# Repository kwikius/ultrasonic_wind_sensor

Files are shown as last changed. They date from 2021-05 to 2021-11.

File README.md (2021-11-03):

# Ultrasonic Wind Speed and Direction Sensor from a car reversing kit and an Arduino.

Ultrasonic wind sensors are known for their accuracy and reliability. However they also tend to be quite expensive.

The Ultrasonic wind sensor described here can be built for around £20($20) and has excellent performance.

The main components of the project are an Ebay car reversing kit, available for around £9(10$US) and an arduino Pro Mini or clone for around 5$US.

Click the below image to watch a video of the project on YouTube:

[Youtube - Ultrasonic Wind Speed and Direction Sensor from a car reversing kit](https://www.youtube.com/watch?v=_kloM0Tk8lo&list=PL-N-nQ0dVeh7bO8eM10oHQ2tNhluuLc5f 
"Youtube - Ultrasonic Wind Speed and Direction Sensor from a car reversing kit")

Full details about building the electronics and mechanical hardware can be found at Hackaday.io

https://hackaday.io/project/181677-wind-sensor-using-car-reversing-kit

The project is designed to be managed in the Arduino IDE.

### Installing and building the project

Firstly clone the Github Project

```>$ git clone https://github.com/kwikius/ultrasonic_wind_sensor.git ```

Next install the quan-trunk submodule using the following command

```>$ git submodule update --init --recursive```

-------------------------

### Building and uploading the Atmega326 part of the Project

Start the Arduino IDE. Click on 'File > Preferences' and modify the sketchbook location so that it leads to the ultrasonic_wind_sensor directory.
Close Arduino and reopen.

When Arduino reopens , click on 'File > Open' , navigate to the ultrasonic_wind_sensor/ArduUltrasonicWindSensor subdirectory and select "ArduUltrasonicWindSensor.ino".

Next click on 'Tools > Board' and select   (AVR boards) > "Arduino Pro or Pro Mini".

Next click on 'Tools > Processor' and select "ATmega328P(5v, 16 MHz)"

Now select 'Sketch > Verify/Compile' to compile. 

The code can be uploaded by attaching a serial cable to the Arduino Pro Mini and clicking Sketch > Upload.

By default the sketch provides text output via the serial port.

For [web server](https://github.com/kwikius/ultrasonic_wind_sensor/blob/master/web_server/web_server.ino) ,
uncomment //#define WIND_SENSOR_WEB_SERVER_OUTPUT in ArduUltrasonicWindSensor.ino

------------------------------

TODO Proper installation instructions for [web server](https://github.com/kwikius/ultrasonic_wind_sensor/blob/master/web_server/web_server.ino)

### Building and uploading the web server.

Assumes you are using the ESP-01. You will need a suitable programming fixture, 
[such as described here](https://www.allaboutcircuits.com/projects/flashing-the-ESP-01-firmware-to-SDK-v2.0.0-is-easier-now/)

You also need to install the ESP8266 plugin for Arduino if not already installed, 
[as described here](https://create.arduino.cc/projecthub/electropeak/getting-started-w-nodemcu-esp8266-on-arduino-ide-28184f)

You need the following libraries in libraries subdirectory 
* https://github.com/me-no-dev/ESPAsyncTCP
* https://github.com/me-no-dev/ESPAsyncWebServer
* https://github.com/Links2004/arduinoWebSockets

Start the Arduino IDE. Click on 'File > Preferences' and modify the sketchbook location so that it leads to the ultrasonic_wind_sensor directory.
Close Arduino and reopen.

When Arduino reopens , click on 'File > Open' , navigate to the ultrasonic_wind_sensor/web_server subdirectory 
and select "web_server.ino".

Next click on 'Tools > Processor' and select "Generic ESP8266 Module"

Now select 'Sketch > Verify/Compile' to compile. 

To Upload the code, connect the programming fixture via 3.3V Serial cable to your PC.
Insert the ESP-01 in the fixture.
Hold down both the Flash and Reset buttons on the programming fixture with the ESP-01 inserted.
Release the Reset button while keeping Flash button pressed. 

While keeping Flash button pressed. Select 'Sketch > Upload'.

Watch the output from the Arduino IDE. Once it is apparent that the code is uploading, you can release the Flash button, 
as it is only required to be pressed when the ESP-01 boots.

For initial programming of the webserver you will need to use the programming fixture to set the Network parameters.

The WebServer requires the nextwork ID and password to connect to. If there are no saved parameters the web server will ask for those.
N.B If using the Arduino Serial monitor for Serial IO, then set Carriage return as the end of line type and set baud rate at 115,200 baud.
You have the choice to save the network parameters in EEPROM or not. If you choose not to save the parameters, they will be available 
until the web server is reset. If you choose to save the parameters they will be saved in EEPROM and will be used by default at reset.
You can change the network you connect to by pressing Return ('\r') three times in 1st 5 seconds after reset. 
Again if you wish to save the new settings the old network settings will be overwritten, otherwise the settings you entered will be used 
unitil next reset.

Once the network parameters have been saved in EEprom, you can put the ESP-01 back in the wind sensor board.

(Note that you must be running the modified ArduUltrasonicWindSensor.ino for Atmega328 to talk to the webserver as described above)

With the wind sensor powered up, you should see the ESP-01 LED blinking. Once the LED goes out, it indicates the web server is connected to the network

The webserver is designed to support MDNS ( NOTE: Unfortunately this doesnt work in Android)

Open a web browser and enter "windsensor.local" as the URL. 
All being well, you should see the windsensor web page with real time data streaming from the wind sensor.

For Android, you will need to download an App such as [Fing](https://www.fing.com/products/fing-app)

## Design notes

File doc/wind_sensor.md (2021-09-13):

# Ultrasonic Wind speed and direction sensor from car reversing sensor kit and an Arduino Mini

A £10 car sensor reversing kit can be converted into an inexpensive but highly accurate wind speed and direction sensor.

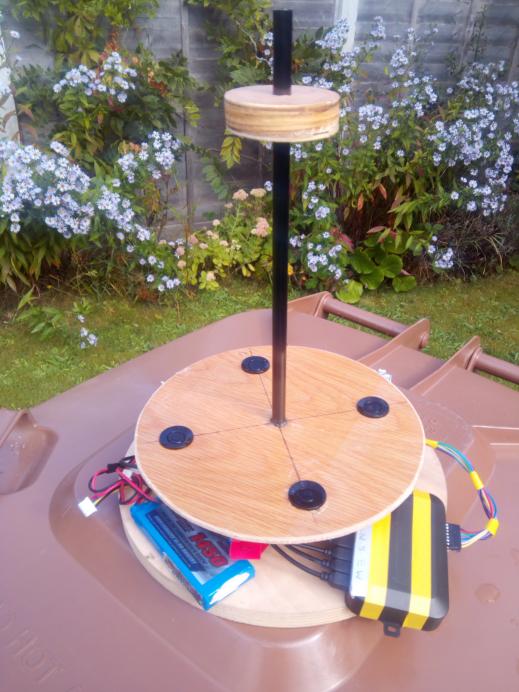
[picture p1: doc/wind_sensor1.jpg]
Ultrasonic Wind speed and direction sensor from car reversing sensor kit


These car reversing kits are abundant on ebay at a low price.

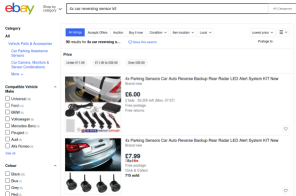
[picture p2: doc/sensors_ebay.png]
Car sensor reversing kits on ebay


In the kit are :

* 4 waterproof 40 kHz ultrasonic transducers with long leads.
* A 12v power supply lead for connecting to a car battery.
* A LED display with long cable on off switch and speaker. (The display has a 14 pin mcu with same pinout as a PIC16C84, but the display is not used in this project.)
* A control box with sockets for the transducers, display and power. 
* A handy hole sawdrill which makes it easy to drill holes for the transducers.

The pcb inside the control box has:
* sockets for 
   * the 4 transducers, 
   * power 
   * 4 wire socket for serial IO ( for the display)
* A pulse transformer for each transducer.
* A multiplexer for the pulse inputs.
* A demultiplexer for the outputs.
* A bandpass filter for filtering the returned signal
* An envelope detector.

The schematic of the transducer circuit :
schematic of the transducer circuit

The schematic of the filter circuit :
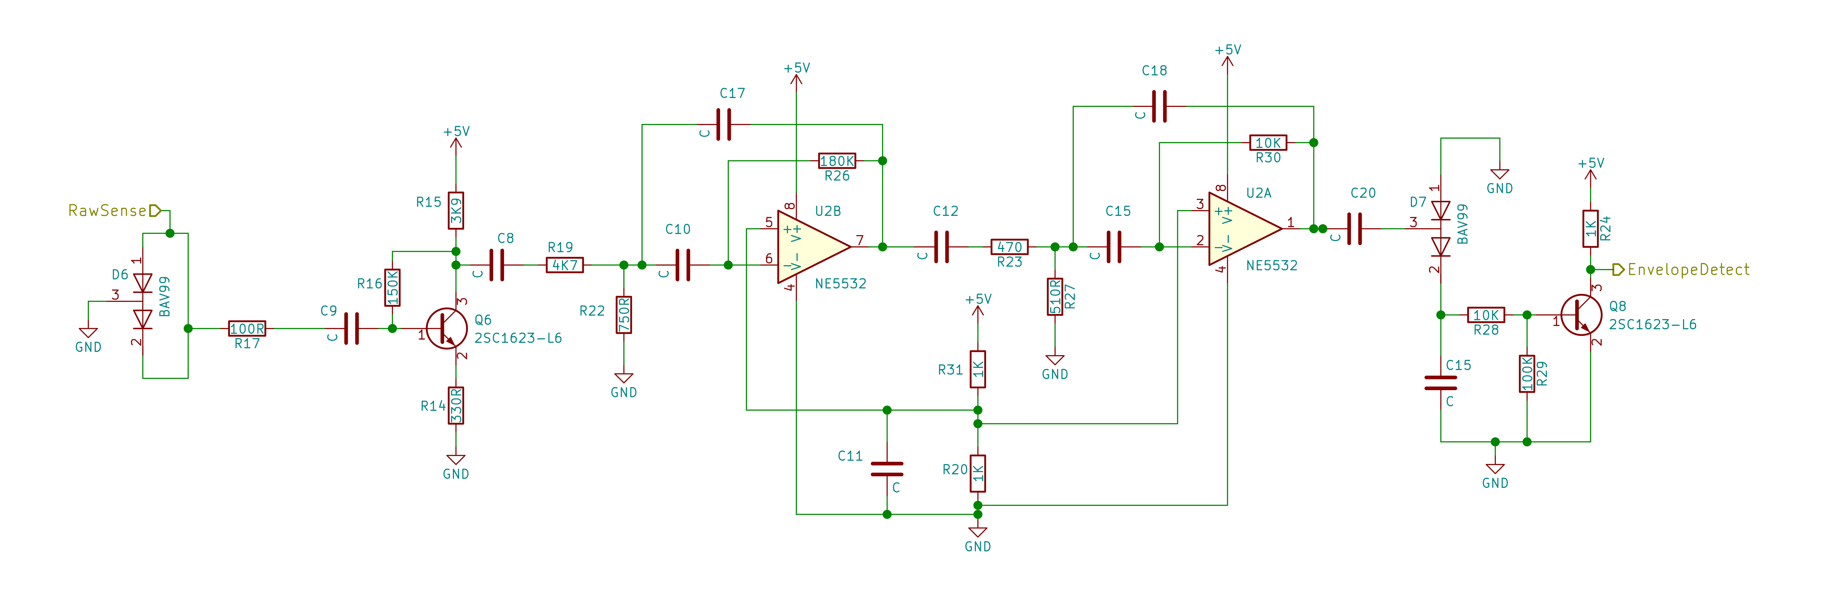
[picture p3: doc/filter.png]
schematic of the filter circuit


There is also an 8 pin mcu on the pcb with same VCC/GND pinout as a PIC12F629.

## Hacking the control board V1

I opted not to try to reprogram the mcu on the pcb, preferring to breakout the required signals to a header hacked on to the PCB.

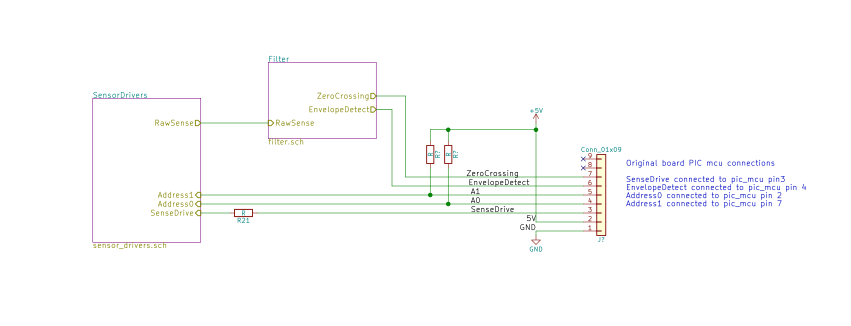
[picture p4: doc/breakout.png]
car sensor breakout connector

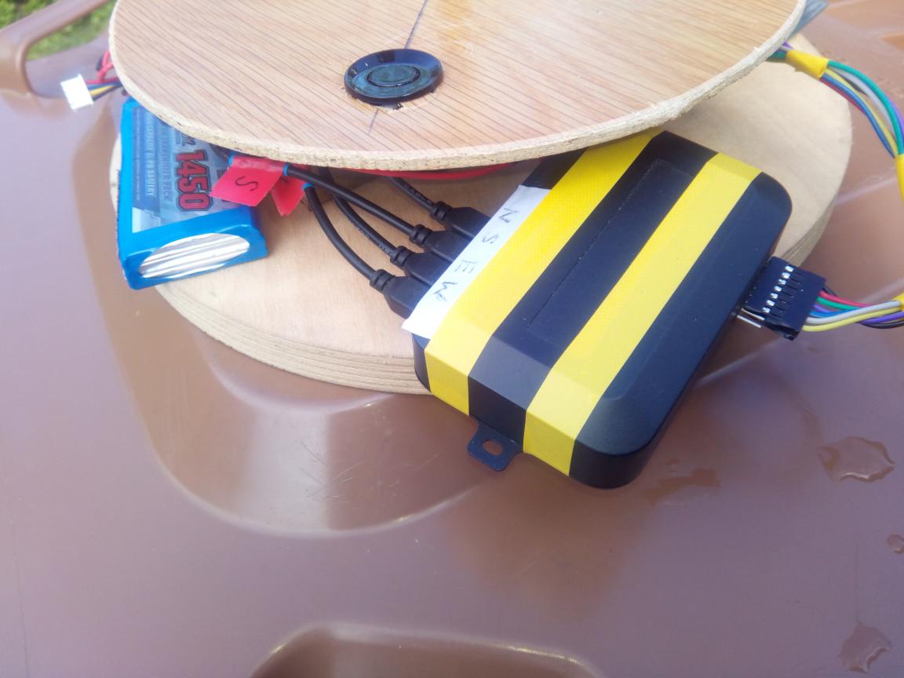
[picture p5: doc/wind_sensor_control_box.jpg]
car sensor control box showing breakout connector [car sensor control box showing breakout connector


Originally I used a [stm32L432 nucleo](https://www.st.com/en/evaluation-tools/nucleo-l432kc.html) which has a clock speed of 80 Mhz, 40 k of ram , 
as well as useful analog peripherals including 5Mbps ADC, 2 comparators and an op-amp on board, but now I have 
[ported the code to an atmega328](../ultrasound_arduino/ultrasound_arduino.ino "arduino sketch"), and am quite pleased with the performance of the wind sensor
driven by the venerable Arduino mcu.

I also used an ESP32 to send the data to a wifi network. At some point  I hope to port the code to the ESP32, so that there will only be a need for one MCU.

These were mounted on a breadboard

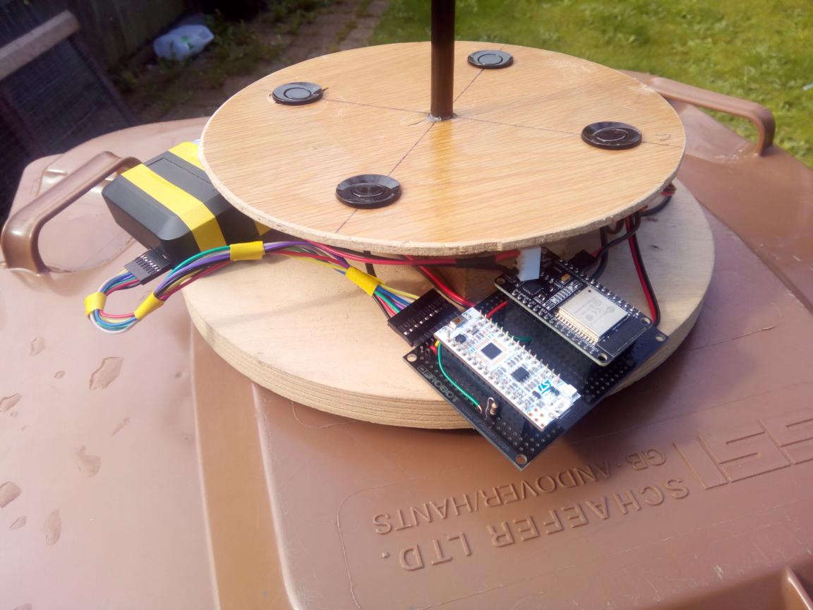
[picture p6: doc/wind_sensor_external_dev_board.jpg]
wind sensor external circuit breadboard


### Required signals V1

Signal | Type | Description | Notes
---|---|---|---
GND| IO | Ground connection |
5V | Out | 5V from board regulator. | 5V regulator cannot provide much current!
A0 | In |transducer address selection bit 0 for IO | Pulled up to 5v for use with 3.3V mcu ( using open drain switch on pins)
A1  | In|  Transducer address selection bit 1 fro IO | Pulled up to 5v for use with 3.3V mcu ( using open drain switch on pins)
EnvelopeDetect| Out| Original envelope using Diodes and BJT | Temperature dependent?
ZeroCrossing | Out | Alternative envelope using comparator based on zero crossing and hysteresis| Provides accurate zero crossing for phase detection
SenseDrive | In | Input to drive the Transducer transformer addressed by A0 A1 | Note this is actually an analog signal fed through the 4052 analog switch. 3.3V should be ok to drive the transformer drive transistor.

I was concerned that the bjt transistor envelope detector at the output of the filter would be quite temperature dependent, which would not affect the direction sensing but may have an effect on the speed. Therefore I opted to roll my own envelope detector using a comparator and breakout out its custom output. This required fitting a little extra circuitry.

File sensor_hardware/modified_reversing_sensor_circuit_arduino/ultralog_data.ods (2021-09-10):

 | north south | south north |  | east west | west east
 | 393.656 | 393.354 | 0.302000000000021 | 394.518 | 394.289 | 0.228999999999985
 | 393.609 | 393.367 | 0.241999999999962 | 394.457 | 394.358 | 0.09899999999999
 | 393.695 | 393.454 | 0.240999999999985 | 394.63 | 394.384 | 0.245999999999981
 | 393.742 | 393.441 | 0.301000000000045 | 394.501 | 394.307 | 0.19399999999996
 | 393.759 | 393.501 | 0.258000000000038 | 394.449 | 394.311 | 0.138000000000034
 | 393.725 | 393.475 | 0.25 | 394.419 | 394.397 | 0.021999999999991
 | 393.647 | 393.341 | 0.305999999999983 | 394.457 | 394.333 | 0.123999999999967
 | 393.703 | 393.445 | 0.257999999999981 | 394.453 | 394.264 | 0.188999999999965
 | 393.643 | 393.389 | 0.253999999999962 | 394.436 | 394.324 | 0.111999999999966
 | 393.725 | 393.35 | 0.375 | 394.651 | 394.333 | 0.317999999999984
 | 393.742 | 393.385 | 0.357000000000028 | 394.483 | 394.315 | 0.168000000000006
 | 393.665 | 393.41 | 0.254999999999995 | 394.462 | 394.285 | 0.176999999999964
 | 393.725 | 393.333 | 0.391999999999996 | 394.518 | 394.264 | 0.253999999999962
 | 393.66 | 393.333 | 0.326999999999998 | 394.397 | 394.289 | 0.108000000000004
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

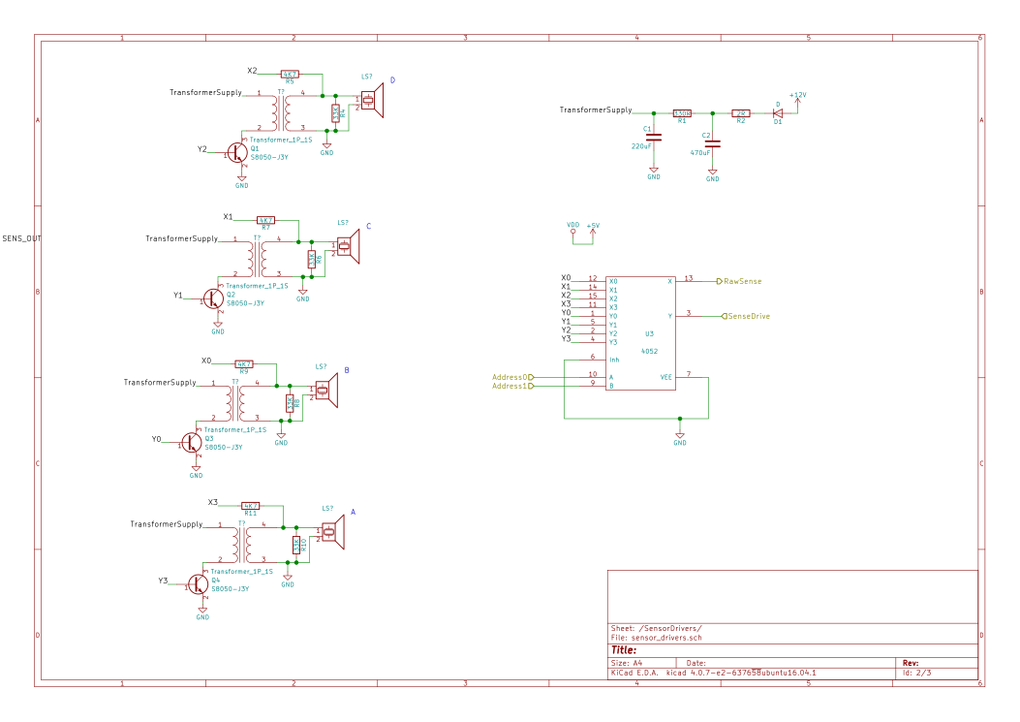
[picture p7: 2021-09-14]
doc/sensor_drivers.sch.png

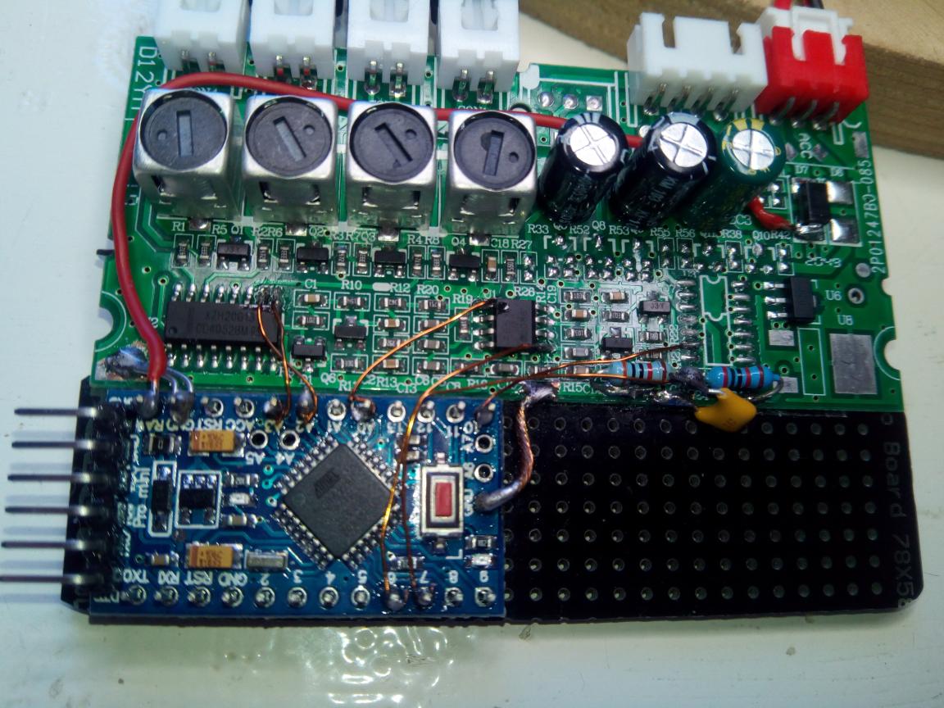
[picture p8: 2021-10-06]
doc/board_connections.jpg

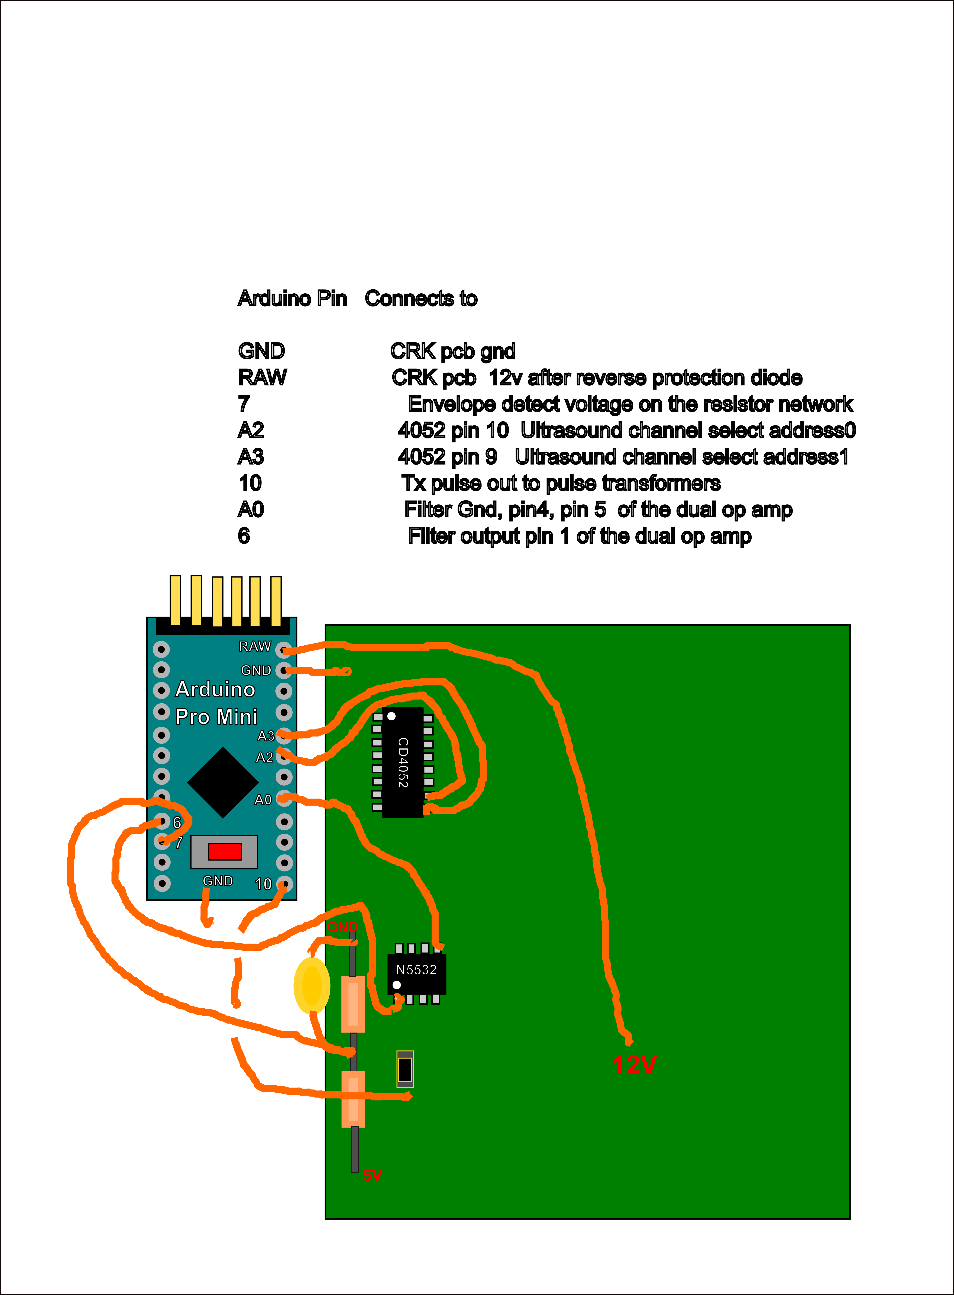
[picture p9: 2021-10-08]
doc/board_connections1.png

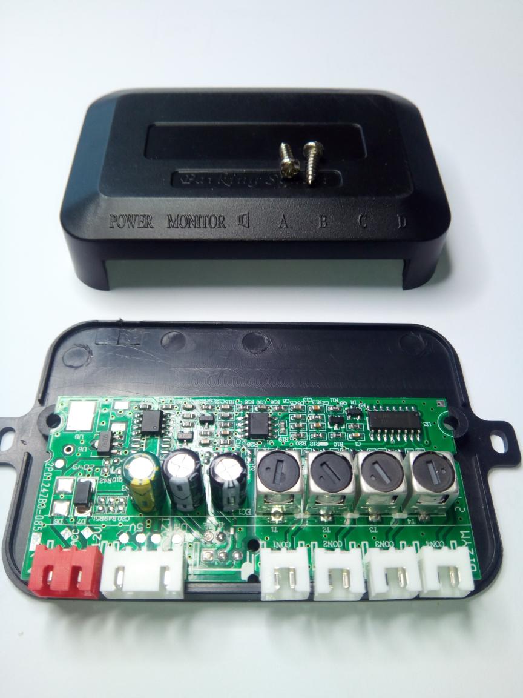
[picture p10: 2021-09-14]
doc/reversing_kit_control_box_inside.jpg

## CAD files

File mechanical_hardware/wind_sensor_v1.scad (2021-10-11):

module transducer()
{
 
   color([0.3,0.3,0.1]){

      difference(){
         union(){
            translate([0,0,-17]){
               cylinder ( d = 21, h = 18, $fn = 20);
            }

            translate([0,0,0]){
               cylinder ( d = 24, h = 1.5, $fn = 20);
            }

            translate([0,6,-18.5]){
               cylinder(d = 6, h = 2, $fn = 20);
            }

            translate([0,6,-(17 + 10)]){
               cylinder(d = 3, h = 10, $fn = 20);
            }
         }
         translate([0,0,0,]){
            cylinder ( d = 12,h = 3,$fn = 20);
         }
      }
   }

}


show_transducer = true;

module housing(angle)
{

 transducer_depth = 30;
 tube_length = 30;
   if (show_transducer){
         rotate([angle,0,0]){
           translate([0,0,30]){
           transducer();
         }
      }
   }
  difference(){
   union(){
      sphere( d = 25);
      rotate([angle,0,0]){
        cylinder(d = 25, h = transducer_depth);
      }
      rotate([90,0,0]){
         cylinder( d = 15, h = tube_length);
      }
   }
   union(){
      sphere( d = 21);
      rotate([angle,0,0]){
         translate([0,0,1]){
           cylinder(d = 22, h = transducer_depth + 2);
         }
      }
      rotate([90,0,0]){
        translate([0,0,-1]){
          cylinder( d = 12, h = tube_length + 2);
       }
      }
   }
  }

}

module bun(radius, thickness)
{
   rotate_extrude(){
      union(){
      translate([0,-thickness/2,0]){
         square([radius, thickness]);
      }
      translate([radius,0,0]){
        circle( d = thickness, $fn = 50);
      }
      }
   }
}

module sensor_hub(){

  hull(){
  scale([1,1,0.3]) {
   sphere(d = 165, $fn = 100);
  }
  translate([0,0,20]){
    bun(60,15);
  }
  }
}

module spine()
{
  translate([0,0,-280]){
   cylinder ( d = 15, h = 300);
  }
  translate([0,0,-(280 + 210)]){
   cylinder ( d = 25, h = 300);
  }
}

module solar_panel()
{
  r_inner = 20;
  r_outer = 60;
  l_inner = 7;
  l_outer = 25;
  polygon( points = [
   [r_inner,l_inner/2],
   [r_inner,-l_inner/2],
   [r_outer,-l_outer/2],
   [r_outer,l_outer/2]
  ]);
}

module solar_panels()
{
  num_elements = 14;
  angle = 360/num_elements;
color("blue"){
  for ( i = [0:1:num_elements]){
    rotate([0,0,angle * i ]){
      solar_panel();
    }
  }
}
}

module echo_plate()
{
   radius = 30;
   thickness = 20;

   bun(radius, thickness);
}

sensor_hub();
rotate([180,0,0]){
for ( i = [0:1:3]){
rotate( [0,0,90 * i]){
translate([0, 110,0]){
housing(35);
}
}
}
}

spine();

translate([0,0, -180]){
   echo_plate();
}

translate([0,0,28]){
 solar_panels();
}

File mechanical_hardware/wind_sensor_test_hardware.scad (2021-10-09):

module transducer()
{
   color([0.3,0.3,0.1]){

      difference(){
         union(){
            translate([0,0,-17]){
               cylinder ( d = 21, h = 18, $fn = 20);
            }

            translate([0,0,0]){
               cylinder ( d = 24, h = 1.5, $fn = 20);
            }

            translate([0,6,-18.5]){
               cylinder(d = 6, h = 2, $fn = 20);
            }

            translate([0,6,-(17 + 10)]){
               cylinder(d = 3, h = 10, $fn = 20);
            }
         }
         translate([0,0,0,]){
            cylinder ( d = 12,h = 3,$fn = 20);
         }
      }
   }

}


transducer_z_spacing = 250;

//transducer_radius_from_center = sqrt(2* pow(transducer_xy_spacing/2,2));
transducer_radius_from_center = 75;

transducer_xy_spacing = 2* transducer_radius_from_center * sin(45);

flight_distance = 2 * sqrt(
   pow(transducer_radius_from_center,2) + pow(transducer_z_spacing,2));

echo("flight distance = " , flight_distance, "mm");

module transducer_arrange(){
  for ( i = [-1:2:1]){
     for( j = [-1:2:1]){
        translate([i * transducer_xy_spacing / 2,j * transducer_xy_spacing / 2, 0]){
           rotate([0,0, -atan2(i,j)]){
              children();
           };
        }
     }
  }
}

module transducer_mount()
{
   difference(){
      //cube([transducer_xy_spacing + 50,transducer_xy_spacing + 50, 3], center =  true);
      cylinder(d = transducer_radius_from_center*2 + 50, h = 3, $fn = 50);

      translate([0,0,-10]){
         transducer_arrange(){
            cylinder(d = 25, h = 25, $fn = 20);
         }
      }
   }

   // echo plate
   translate([0,0,transducer_z_spacing]){
     cylinder ( d = 62, h = 6,$fn = 50);
   }
   // stem
   translate([0,0,-20]){
   cylinder( d= 10, h = transducer_z_spacing + 20);
   }

   // stem mount
   translate([0,0,-18]){
     cylinder ( d = 50, h = 18,$fn = 50);
   }
}

transducer_mount();

translate([0,0,3]){
  transducer_arrange()
    rotate([0,0,0]){
    transducer();
    }
}

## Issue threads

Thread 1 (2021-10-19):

windsensor_packet library missing

mrrco-gh, 2021-10-19:
Arduino code  includes windsensor_packet.h, but file (and library ?) is missing.
Thanks

kwikius, 2021-10-20:
@mrrco-gh  Thanks for the notification. I added the missing library. Will provide proper details for installing web libraries when I have time.

I also modified the sketch so that by default text is output in user readable format.

Closed 2021-10-20.

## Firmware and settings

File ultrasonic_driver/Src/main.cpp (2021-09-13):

#include <string.h>
#include "usart.h"
#include "adc.h"
#include <quan/conversion/float_to_ascii.hpp>
#include <quan/fixed_quantity/literal.hpp>
#include <quan/time.hpp>
#include <quan/velocity.hpp>
#include <quan/length.hpp>
#include <quan/area.hpp>
#include <quan/frequency.hpp>
#include <quan/acceleration.hpp>
#include <quan/angle.hpp>
#include <quan/fixed_quantity/operations/atan2.hpp>
#include <quan/two_d/vect.hpp>
#include "resource.hpp"
#include "../../libraries/windsensor_packet/windsensor_packet.h"

namespace {

   QUAN_QUANTITY_LITERAL(time,us)
   QUAN_QUANTITY_LITERAL(length,mm)
   QUAN_QUANTITY_LITERAL(area,mm2)
   QUAN_QUANTITY_LITERAL(velocity,m_per_s)
   QUAN_QUANTITY_LITERAL(acceleration,m_per_s2)
   QUAN_QUANTITY_LITERAL(frequency,Hz)
   QUAN_QUANTITY_LITERAL(angle,deg)
}

void setup();

void setup_ultrasonic_pulse_stream();

bool get_envelope_capture(quan::time::us (& result)[4]);

namespace
{
   // TODO: add a temperature sensor and use that to adjust sound velocity
   quan::velocity::m_per_s sound_velocity = 344.7_m_per_s;
   // measurement uncertainty of flight distance measurements
   // statistical variance or standard_deviation ^ 2

   // from a random sample of measurements
 //  quan::length::mm flight_distance_measurement_standard_deviation = 0.2_mm;
  // quan::time::us tof_measurement_std_dev = 0.8_us;

   // a random variable representing how much the wind varies
   quan::acceleration::m_per_s2 wind_accel_std_dev = 1_m_per_s2;

   // horz sensor to center distance
   quan::length::mm radius = 75_mm;

   quan::length::mm height = 128_mm;

   quan::angle::rad const flight_angle  = quan::atan2(height, radius);
   auto flight_distance = 2 * quan::sqrt(quan::pow<2>(radius) + quan::pow<2>(height));

   // mean error in random sample when measuring nominal windless condition
   // use the cal function to find this out
   // TODO auto cal?
   quan::time::us north_south_bias = 1.31_us;
   quan::length::mm north_south_distance = flight_distance;

   quan::time::us east_west_bias = 0.92_us;
   quan::length::mm east_west_distance = flight_distance;

   quan::frequency::Hz tof_update_frequency = 50_Hz/4.0;

   // Time taken in filter from actual start of pulse to comparator falling edge
   quan::time::us rise_time = 98_us;
   // std dev of risetime is probably base on  1/ ultrasound frequency
   //quan::time::us rise_time_std_dev = 98_us;

   quan::velocity::m_per_s solve_wind_velocity(  quan::time::us const & tF, quan::time::us const & tR)
   {
      if ( (tF > 1_us) && ( tR > 1_us) ){
          return flight_distance / (2 * cos(flight_angle)) * ( 1 / tF - 1 / tR);
      }else{
         return 0_m_per_s;
      }
   }

   quan::velocity::m_per_s solve_wind_velocity_north_south( quan::time::us const * results)
   {
      auto const tF = results[0] - (rise_time + north_south_bias/2.f);
      auto const tR = results[1] - (rise_time - north_south_bias/2.f);

      return solve_wind_velocity(tF, tR);
   }

   quan::velocity::m_per_s solve_wind_velocity_east_west( quan::time::us const * results)
   {
      auto const tF = results[0] - (rise_time + east_west_bias/2);
      auto const tR = results[1] - (rise_time - east_west_bias/2);

      return solve_wind_velocity(tF, tR);
   }

   // timing with no correction
   // for calibration in still conditions
   void raw_timing_output()
   {
      while (1) {
         quan::time::us results[4];
         while ( !get_envelope_capture(results)) { asm volatile ("nop":::);}

         auto output = [] (const char * str, quan::time::us const & t ){
            serial::port::write(str);
            char buf[50] = "";
            quan::float_to_ascii<3>(t.numeric_value(),buf);
            serial::port::write(buf);
            serial::port::write(" us\n");
            serial::port::flush_tx();
         };

         output("NS = ",results[0]);
         output("SN = ",results[1]);

         output("EW = ",results[2]);
         output("WE = ",results[3]);

         serial::port::write("----------\n");
      }  
   }


   void filtered_raw_timing_output(float filter_gain)
   {
      
      quan::time::us filtered_results [4] = {0_us};

      // initial estimate is initial measurement
      for ( uint32_t i = 0U; i < 2U; ++i){
         // ignore first result set
         while ( !get_envelope_capture(filtered_results)) { asm volatile ("nop":::);}
      }

      while (1) {
         quan::time::us results[4];
         while ( !get_envelope_capture(results)) { asm volatile ("nop":::);}

         for ( uint32_t i = 0; i < 4; ++i){
            filtered_results[i] += filter_gain * ( results[i] - filtered_results[i]);
         }

         auto output = [] (const char * str, quan::time::us const & t ){
            serial::port::write(str);
            char buf[50] = "";
            quan::float_to_ascii<3>(t.numeric_value(),buf);
            serial::port::write(buf);
            serial::port::write(" us\n");
            serial::port::flush_tx();
         };

         output("NS = ",filtered_results[0]);
         output("SN = ",filtered_results[1]);
         output("NS diff = ",filtered_results[0]- filtered_results[1]);
         output("EW = ",filtered_results[2]);
         output("WE = ",filtered_results[3]);
         output("EW diff = ",filtered_results[2]- filtered_results[3]);
         serial::port::write("----------\n");
      }  
   }

   // x is EastToWest and y is NorthToSouth
   // so [0 m/s,1 m/s] means from due north
   // [0 m/s,-1 m/s] from due south
   // [ 1 m/s, 0 m/s] from due east
   // [0 m/s , -1 m/s] fromdue west
   // result 0 deg means blowing from due north t
   // 90 deg means blowing from due east
   //etc
   quan::angle::deg get_wind_direction(quan::two_d::vect<quan::velocity::m_per_s> const & v)
   {
      quan::angle::deg wind_direction  = quan::atan2(v.x,v.y);

      if ( wind_direction < 0_deg){
         wind_direction += 360_deg;
      }
      return wind_direction;
   }

   quan::velocity::m_per_s get_wind_speed(quan::two_d::vect<quan::velocity::m_per_s> const & v)
   {
      return quan::two_d::magnitude(v);
   }

   struct wind_sensor{

      using wind_speed_vect_t = quan::two_d::vect<quan::velocity::m_per_s>;

      // blocks
      // call once at startup
      static void init()
      {
         quan::time::us results [4] = {0_us};
         //ignore first
         while ( !get_envelope_capture(results)) { asm volatile ("nop":::);}

         while ( !get_envelope_capture(results)) { asm volatile ("nop":::);}

         // initial estimate is same as measurement
         
         estimate = { 
            solve_wind_velocity_east_west(results + 2U) ,
            solve_wind_velocity_north_south(results)
         };
         // TODO: initial estimate_uncertainty = measurement_uncertainty
      }

      // blocks waiting for update : TODO RTOS
      static void update()
      {
         wind_speed_vect_t const prediction = estimate;

         quan::time::us results [4] = {0_us};
         while ( !get_envelope_capture(results)) { asm volatile ("nop":::);}

            wind_speed_vect_t measurement = { 
               solve_wind_velocity_east_west(results + 2U) ,
               solve_wind_velocity_north_south(results)
            };

         float const kalman_gain = 0.1; //estimate_uncertainty / (estimate_uncertainty + measurement_uncertainty);

         estimate = prediction + kalman_gain * ( measurement - prediction);

      }

      static quan::velocity::m_per_s get_wind_speed()
      {
         return ::get_wind_speed(estimate);
      }

      static quan::angle::deg get_wind_direction()
      {
         return ::get_wind_direction(estimate);
      }

    private:
         static wind_speed_vect_t estimate;         
   };

   // call init?
   wind_sensor::wind_speed_vect_t wind_sensor::estimate;

   template <typename Packet>
   void send_packet( Packet const & packet)
   {
      uint8_t encoded[quan::uav::cobs::get_encoded_length<sizeof(packet)>()];
      quan::uav::cobs::encode (packet.ar,sizeof(packet),encoded);

      serial::port::put('\0'); // frame
      serial::port::write(reinterpret_cast<char*>(encoded),sizeof(encoded));
      serial::port::put('\0'); // frame
   }

   template <typename Packet, typename... ValueTypes>
   void send_packet( ValueTypes const &... values )
   {
      Packet packet{values...};
      send_packet(packet);
   }

   void wind_velocity_output()
   {
      wind_sensor::init();
      uint32_t iter = 0U;
      for(;;){

         wind_sensor::update();

         ++iter;
         // show we are running
         if ((iter % 10 ) == 0){
             quan::stm32::complement<led>();
         }

         auto const speed = wind_sensor::get_wind_speed();
         auto const direction = wind_sensor::get_wind_direction();

         send_packet<velocity_and_direction_packet>(speed,direction);
      }
   }


}// namespace

int main(void)
{
  setup();

  serial::port::write("stm32L4 ultrasonic detector test\n");
  
  setup_ultrasonic_pulse_stream();

 // raw_timing_output();
  wind_velocity_output();
  //filtered_raw_timing_output(0.1);
}

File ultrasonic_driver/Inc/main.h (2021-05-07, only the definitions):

#define MCO_Pin LL_GPIO_PIN_0
#define MCO_GPIO_Port GPIOA
#define VCP_TX_Pin LL_GPIO_PIN_2
#define VCP_TX_GPIO_Port GPIOA
#define SWDIO_Pin LL_GPIO_PIN_13
#define SWDIO_GPIO_Port GPIOA
#define SWCLK_Pin LL_GPIO_PIN_14
#define SWCLK_GPIO_Port GPIOA
#define VCP_RX_Pin LL_GPIO_PIN_15
#define VCP_RX_GPIO_Port GPIOA

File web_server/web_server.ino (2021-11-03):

#include <stdlib.h>

#if defined ESP8266
   #include <ESP8266WiFi.h>
   #include <ESP8266mDNS.h>   
#else
   #if defined ESP32
      #include <WiFi.h>
      #include <ESPmDNS.h>
   #else
      #error unknown processor
   #endif
#endif

#include <WebSocketsServer.h> 
  
#include <userin.h>
#include <builtin_led.h>
#include <web_pages.h>
#include <quan.h>

#include <windsensor_packet.h>

#if defined ESP8266
   HardwareSerial& debugSerial = Serial;
   HardwareSerial& sensorSerial = Serial;
#else
   #if defined ESP32
      HardwareSerial& debugSerial = Serial;
      HardwareSerial& sensorSerial = Serial2;
   #else
      #error need to define serial ports 
   #endif
#endif

namespace {

   uint16_t constexpr basePort = 80;

   // N.B.  no spaces or underscores in hostname
   constexpr char wifiHostName[] = "USWS-Server";
   constexpr char mdns_local_name[] = "windsensor";

   void webSocketEvent(byte /*num*/, WStype_t /*type*/, uint8_t * /*payload*/, size_t /*length*/)
   {
     // todo upload data to server
   }

   WiFiServer server(basePort);
   WebSocketsServer webSocket = WebSocketsServer(basePort + 1);

   void WifiConnect()
   {

     WiFi.hostname(wifiHostName);

     setup_network_params();

     WiFi.begin(get_wifi_network_ssid(), get_wifi_password());
     debugSerial.print("Connecting to ");
     debugSerial.print(get_wifi_network_ssid());
     debugSerial.print("...");
     while (WiFi.status() != WL_CONNECTED) {
       delay(250);
       complement_builtin_led();
       debugSerial.print(".");
     }

     turn_off_builtin_led();
     debugSerial.println('\n');
     debugSerial.print("Connected to : ");
     debugSerial.println(WiFi.SSID());       
     debugSerial.print("IP address   : ");
     debugSerial.println(WiFi.localIP());         

     if (!MDNS.begin(mdns_local_name)) { 
        debugSerial.println("Error setting up MDNS responder!");
     }
     debugSerial.println("MDNS responder started");
     MDNS.addService("http", "tcp", basePort); 
     debugSerial.print("Web page available as ");
     debugSerial.print(mdns_local_name);
     debugSerial.println(".local\n");
    
     server.begin();
     webSocket.begin();


     webSocket.onEvent(webSocketEvent);

   }

    static const uint8_t atmega328Reset = 0;
}

void setup() 
{
   debugSerial.begin(115200);
   // debugSerial and sensorSerial may be 2 separate ports
   if ( &debugSerial != &sensorSerial){
      sensorSerial.begin(115200);
   }
   builtin_led_setup();

   pinMode(atmega328Reset, OUTPUT);
   digitalWrite(atmega328Reset,LOW);

   WifiConnect();

   digitalWrite(atmega328Reset,HIGH);
}

namespace{

   void send_not_found_response(WiFiClient & client)
   {
      client.println("HTTP/1.1 404 Not Found");
      client.println("Connection: close");
      client.println();
   }

   struct uri_service{
      const String uri;
      void (*service)(WiFiClient & client);
   };

   uri_service services[] = {
      { "/", 
        [] (WiFiClient & client) { 
           serve_page(client,"text/html",get_web_page_main_html());
         }
      },
      { "/compass.js", 
        [] (WiFiClient & client) { 
           serve_page(client,"text/javascript",get_web_page_compass_js());
         }
      }
   };

   bool service(WiFiClient & client, String const & uri)
   {
      for (auto const & srv : services){
         if ( uri == srv.uri){
            srv.service(client);
            return true;
         }
      }
      return false;
   }

   void processGET(WiFiClient & client)
   {
      if (client) {                             
         debugSerial.println("New Client.");            
         String request;          
         bool newline = false;
         while (client.connected()) {           
            if (client.available()) {             
               char const c = client.read();             
               debugSerial.write(c);                    
               request += c;
               String filename;
               switch (c){
                  case '\r':
                     break; // ignore
                  case '\n':
                     if (newline){
                        // 2 X newline so end of header. Process the header
                        bool serviced = false;
                        int const get_pos = request.indexOf("GET /");
                        if (get_pos >= 0){
                           int const end_address = request.indexOf(" ",get_pos + 4);
                           if ( end_address >= 0){
                              filename = request.substring(get_pos + 4,end_address);
                              serviced = service(client,filename);
                           }
                        }
                        if (!serviced){
                           debugSerial.print(filename);
                           debugSerial.println(" not found\n");
                           send_not_found_response(client);
                        }
                        client.println();
                        client.stop();
                     }else{
                        newline = true;
                     }
                     break;
                  default:
                     newline = false;
                     break;
               } //~switch
            }// ~if
         }//~while
         debugSerial.println("Client disconnected.");
         debugSerial.println("");
      }//~if
   }

   quan::uav::cobs::static_packet_parser<
      quan::uav::cobs::get_encoded_length<sizeof(velocity_and_direction_packet)>()
   > parser;

   void parse_input()
   {
      while(sensorSerial.available() ){ 
         uint8_t const ch = sensorSerial.read();
         uint16_t const packet_length = parser.parse(ch);
         if ( packet_length > 0U ){
            uint8_t const * decoded_packet_buffer = parser.get_decoded_packet();
            uint16_t const packet_id = static_cast<uint16_t>(decoded_packet_buffer[0]) 
            + (static_cast<uint16_t>(decoded_packet_buffer[1]) << 8U);
            if ( static_cast<PacketID>(packet_id) == PacketID::WindSpeedAndDirection){
               if ( !quan::tracker::zapp4::decode_packet<velocity_and_direction_packet>(
                     packet_length, parser,
                     [](velocity_and_direction_packet const & p ){
                        String const text = "{\"windspeed\":" + String(p.values.speed.numeric_value(),2) + 
                        ", \"windangle\":" + String(p.values.direction.numeric_value(),1) + "}";
                        webSocket.broadcastTXT(text.c_str());
                     }
                  )
               ) {
                  debugSerial.println("parse packet failed");
               }
            }
         }
      }
   }
} // ~namespace

void loop(){

#if defined ESP8266
   MDNS.update();
#endif
   parse_input();

   webSocket.loop();

   WiFiClient client = server.available();
   if ( client){ 
      processGET(client);
   }
}

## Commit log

2021-08-29 use arduino symbolic constant for builtin led constant
2021-08-29 Now working OK with ESP32 (ESP32DEVKITV1 dev board)
2021-09-02 Use refernces for serial ports so can use different for esp32 etc
2021-09-10 add sensor sim and schematics and arduino code, though not working well atm
    [filter.sch, reversing_sensor_circuit.kicad_pcb, reversing_sensor_circuit.sch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]
2021-09-10 Timer1 now stopping OK. Seems to require writing to lowest bits of TCCR1A in diasbleTIM1 fun
2021-09-10 Seem to be getting a pulse, but need to setup pin as output and test on scope
2021-09-12 redo timing. Wasnt working due to double buffering
    [simulated_pulse.ods]
2021-09-12 arduino : In main loop, move raw print to function
2021-09-14 make specific atmega328 version
    [atmega328p_mcu.sch, filter.sch, reversing_sensor_circuit.kicad_pcb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]
2021-09-30 mods to schematic
    [atmega328p_mcu.sch, filter.sch, sensor_drivers.sch]
2021-09-30 use two alternating buffers for samples , so that there is no need to disable interrupts to read the samples
2021-10-02 internal comparator option1, with a feedback on the positive input, but not tested yet
    [atmega328p_mcu.sch]
2021-10-03 update schematic with internal comp
    [atmega328p_mcu.sch]
2021-10-05 now working with internal comparator. Previosu problems were due to psu. With better cictuit implementation, separation of power supplies of arduino and car reversing pcb, seems to work OK
    [ultrasound_arduino.ino]
2021-10-08 use polledSerial which doesnt use uart interrupts, rather than standard Arduino.Serial
    [atmega328p_mcu.sch, filter.sch, reversing_sensor_circuit.sch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]
2021-10-09 add readme and scad cad files
    [wind_sensor_test_hardware.scad, wind_sensor_v1.scad]
2021-10-11 modify web server to put arduino in reset while connecting, to reduce emi
    [wind_sensor_v1.scad]
2021-10-20 include wind_sensor_packet per https://github.com/kwikius/ultrasonic_wind_sensor/issues/1
2021-10-20 modify arduino sketch for simple text output by default, that doesnt need web server
2021-11-03 update readme and add wifi circuit details
    [atmega328p_mcu.sch, filter.sch, reversing_sensor_circuit.sch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]

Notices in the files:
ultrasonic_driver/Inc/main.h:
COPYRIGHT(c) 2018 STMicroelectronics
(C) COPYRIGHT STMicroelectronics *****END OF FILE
